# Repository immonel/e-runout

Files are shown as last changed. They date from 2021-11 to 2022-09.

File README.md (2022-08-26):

# e-runout

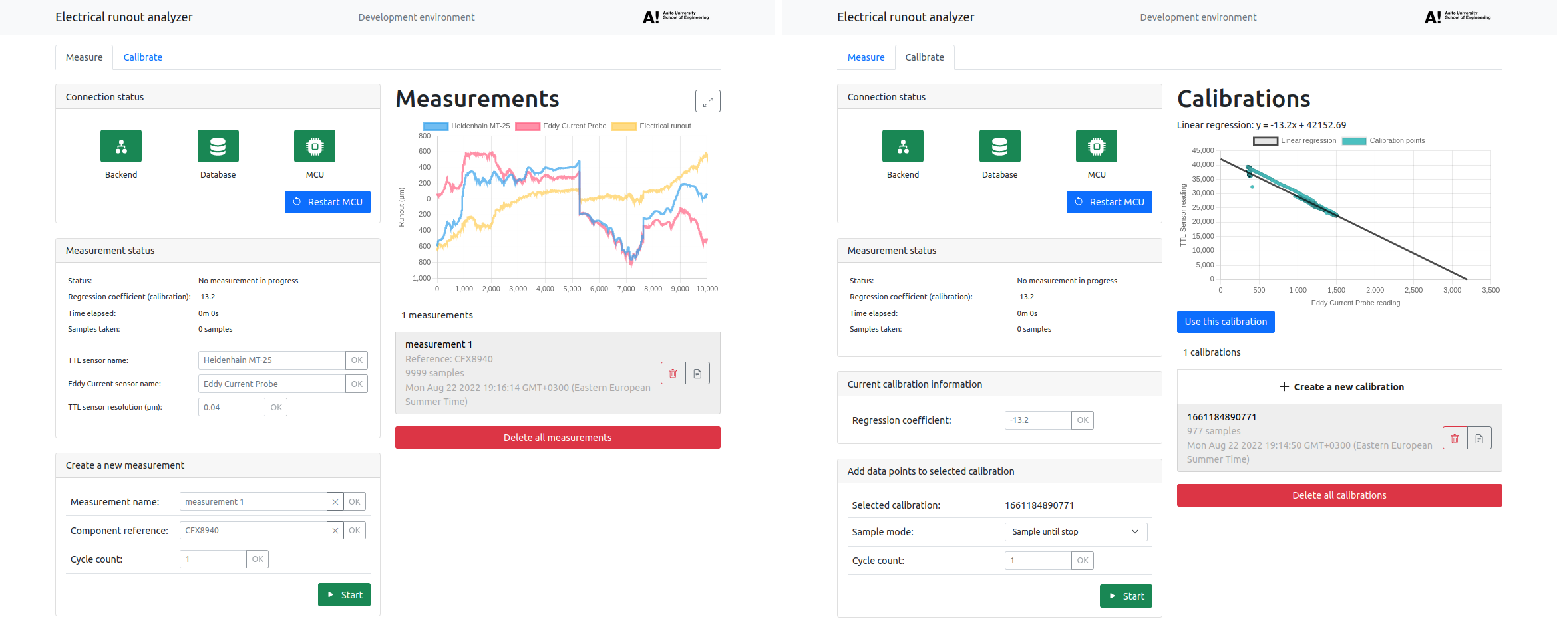
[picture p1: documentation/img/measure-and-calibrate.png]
Screenshot of the app


This project is used to measure electrical runout by comparing measurements from touching probe sensors and Eddy current probes simultaneously.

Technologies and frameworks used in the project include Docker, React, Redux, Bootstrap, Node.js, Express, MongoDB and Socket.IO.

### Project structure
[client/](client/)  
Frontend React app code

[documentation/](documentation/)  
Documentation files

[hardware/](hardware/)  
PCB schematics

[mongodb/](mongodb/)  
MongoDB init scripts

[server/](server/)  
Backend Node.js app code

[teensy/](teensy/)  
Teensy microcontroller C++ code

----
## Getting started

### Production

1. Fill out environment variables and rename the .env file:
```sh
$ mv .example.env .env
```

2. Start up the docker-compose stack:
```sh
$ docker-compose up
```

**NOTE:** Please keep in mind that buiding the `erunout` Docker image on Raspberry Pi will take a LONG time (~1h).

The application creates a Wi-Fi access point with environment variables `SSID` and `PASSPHRASE` given in the `.env` file.

IP address for the application is `10.0.10.1` by default and can be accessed after connecting to the WLAN network.

```
TODO: WAN access is currently not working on the wireless access point
```

### Development

1. Rename the .env file:
```sh
$ mv .env.example .env
```

2. Start up the development database:
```sh
$ docker-compose -f docker-compose.dev.yml up
```

3. Start up the development backend server (in the `server` folder):
```sh
server $ npm install
server $ npm run dev
```

4. Start up the development frontend server (in `client` folder):
```sh
client $ npm install
client $ npm start
```

5. Navigate to the development app at `localhost:3001`. The backend server is accessible from `localhost:3000` and the database admin interface from `localhost:8081`.

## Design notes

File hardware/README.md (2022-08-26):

# PCB schematics

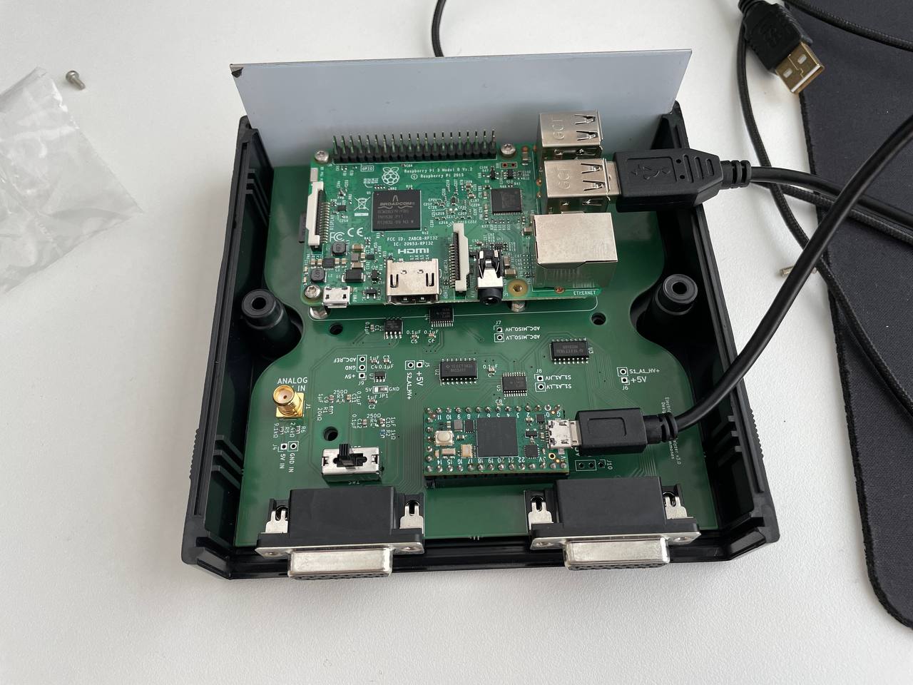
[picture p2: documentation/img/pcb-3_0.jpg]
Image of the PCB


This folder contains the KiCad (6.0) schematics for the project. The most recent schematics are named `erun2`. The project file is `erun2.kicad_pro` which is the easiest way to open all the schematics. The wiring diagram is in `erun2.kicad_sch` and PCB in `erun2.kicad_pcb`.

### Data sheets of components used
- [TXB0108PWR](https://www.ti.com/lit/ds/symlink/txb0108.pdf) Voltage level translator (5V->3.3V)
- [MC3486N](https://www.ti.com/lit/ds/symlink/mc3486.pdf) Differential line receiver
- [MCP3301](https://ww1.microchip.com/downloads/aemDocuments/documents/APID/ProductDocuments/DataSheets/21700E.pdf) 13-bit analog-to-digital converter
- [TPS79147DVBT](https://www.ti.com/lit/ds/symlink/tps79147-ep.pdf) Low-dropout regulator (WARNING: These break really easily due to ESD, be careful with these)

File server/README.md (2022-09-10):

# e-runout server

This Node.js backend uses Socket.IO to communicate with the client and 'serialport' npm package to communicate with the Teensy microcontroller. Measurements are saved into a MongoDB database using the 'mongoose' npm library. More information about the libraries used can be found from [helpful-links.md](../documentation/helpful-links.md). 

## Getting started

### Development

The development server can be started by running `npm install` and `npm run dev`. The default port is 3000.

### Production

The backend server relies on other services to be running. Please refer to the [repository README](../README.md).

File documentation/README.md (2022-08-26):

# Documentation

This folder contains useful information and documentation about the `e-runout` project. Please note, however, that README-files in the root of the project and in subfolders contain most of the technical details:

[README.md](../README.md)  
[client/README.md](../client/README.md)  
[server/README.md](../server/README.md)  
[teensy/README.md](../teensy/README.md)  
[hardware/README.md](../hardware/README.md)

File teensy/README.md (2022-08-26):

# erunout -- Teensy microcontroller

This project uses the Teensy 4.0 microcontroller for reading the sensors, mostly because it has [hardware support](https://forum.pjrc.com/threads/58478-Teensy-4-x-H-W-Quadrature-Encoder-Library) for quadrature signals.

The Teensy will idle until it receives commands through the serial port. Supported commands are:

- `SAMPLE_CYCLES <count>`: Sample integer amount of cycles (full rotary encoder revolutions)
- `SAMPLE_UNTIL`: Sample data points until `STOP` command is received
- `SAMPLE_ONCE`: Sample a single data point and stop
- `STOP`: Stop reading and sending data points
- `REBOOT`: Reboots the microcontroller
- `ZERO`: Resets the touching TTL probe's value to zero.

## Reading the sensors

The TTL signals are read using the [Teensy hardware quadrature library](https://github.com/mjs513/Teensy-4.x-Quad-Encoder-Library). The Eddy current sensor's signal is read using [SPI](https://www.pjrc.com/teensy/td_libs_SPI.html).

## Data point format

The data point is sent to the Raspberry Pi using serial port as follows:

```
+--------------------------------+----------------+----------------+
| TTL sensor                     | Eddy probe     | Cycle          |
| 32 bits                        | 16 bits        | 16 bits        |
+--------------------------------+----------------+----------------+
```

The values are bit shifted into a 64-bit integer and parsed in the Node.js backend. The data points are delimited by a newline characted `\n`.

### Notes about the data format

- `Cycle` indicates the current cycle in a running measurement. It is currently not used in the backend, but it could have use in dividing the measurement into cycles or displaying in the chart where the cycle changes
- The data point is sent through serial with `Serial.println` encoded in ASCII. It is not ideal and the bit shifting is currently kind of useless since the values in the data point could just be delimited with a character, `18423,2495,1` for example. The original purpose was to send the bit-shifted 64-bit integer as binary, but delimiting separate data points reliably (and space efficiently) is not trivial and was left for future implementation.
- Sign of the Eddy current probe value is currently discarded since the negative values in voltage have no meaning in this application.

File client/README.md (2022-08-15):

# Electrical runout analyzer -- frontend

Frontend of the `e-runout` project is a SPA (single page application) built with React and Bootstrap. 

The frontend uses WebSockets to communicate with the backend. ASyncAPI documentation about the WebSocket API can be found in [documentation/asyncapi.yaml](../documentation/asyncapi.yaml). It is recommended to use e.g. [AsyncAPI Studio](https://studio.asyncapi.com/) to view the API documentation.

## The webapp

The webapp contains two pages: `Measure` and `Calibrate`.

### Measure

The `Measure` page is used to create and view measurements. When you press the `Start` button, a new measurement is created with the parameters given in the webapp. Data points are not recorded until the rotary encoder hits the trigger point. After the trigger point, data points are sampled and saved to the new measurement. If either the configured cycle count is reached or the measurement is stopped, the newly created measurement will be added to the measurement list.

**NOTE: Remember to calibrate the Eddy current sensor on the `Calibrate` tab before measuring for the first time!**

### Calibrate

The `Calibrate` page is used to create and view calibrations. **Calibrations use the same data structure internally as regular measurements.** As opposed to the `Measure` page, data points are added to existing calibrations. Thus, you will need to first create an empty calibration and select it to add data points. To set the calibration cofficient, press the `Use calibration` button.

## Getting started
### Development

To start the frontend development server, run the following commands in the `client` folder.

1. `npm install`
2. `npm start`

The development server can be accessed from `localhost:3001` by default.

### Production build

To build a production webapp, run `npm run build` and it will be built into `build` folder. The backend serves contents from this folder in development environment. 

It is recommended, however, to use the production environment using `docker-compose` as described in the project root [README.md](../README.md) file.

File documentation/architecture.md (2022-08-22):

# Architecture

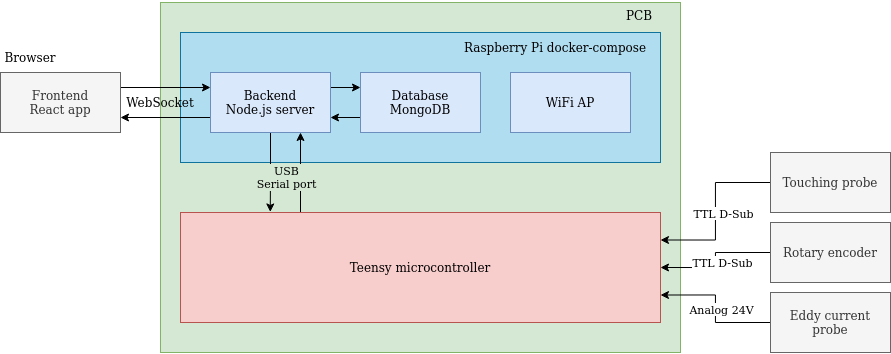
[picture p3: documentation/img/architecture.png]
architecture image


## docker-compose stack

The production `docker-compose` stack consists of three containers:
- `erunout`
- `mongo` [Docker Hub](https://hub.docker.com/_/mongo)
- `rpi-hostap` [Docker Hub](https://hub.docker.com/r/sdelrio/rpi-hostap)

The development `docker-compose` stack consists of two containers:
- `mongo` [Docker Hub](https://hub.docker.com/_/mongo)
- `mongo-express` [Docker Hub](https://hub.docker.com/_/mongo-express)

## erunout

The backend server running on the Raspberry Pi uses WebSockets to communicate with the client. Refer to [AsyncAPI documentation](./asyncapi.yaml) for more detailed information.

## Teensy

The Teensy microcontroller is connected to the Raspberry Pi using USB Serial port.

The TTL signals are connected to Teensy's digital pins supporting hardware quadrature. The analog signal is converted to a digital signal using on-board ADC and passed on to the Teensy using SPI.

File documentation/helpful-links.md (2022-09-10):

# Helpful links to external documentations

- [Heidenhain TTL interface](https://www.heidenhain.fi/fileadmin/pdb/media/img/1078628-23_Interfaces_en_web.pdf)
- [Teensy 4.0](https://www.pjrc.com/store/teensy40.html)
- [Teensy Hardware Quadrature library](https://github.com/mjs513/Teensy-4.x-Quad-Encoder-Library)
- [rpi-hostap](https://github.com/sdelrio/rpi-hostap)
- [React Bootstrap documentation](https://react-bootstrap.github.io/)
- [Full stack open course materials](https://fullstackopen.com/)
- [Socket.IO](https://socket.io/)
- [serialport npm](https://serialport.io/docs/)

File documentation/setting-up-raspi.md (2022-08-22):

# Setting up Raspberry Pi for e-runout

It is recommended to install Ubuntu Server for running the application. Note that internet connection is required to pull the repository and Docker images.

### Pulling the repository

```sh
$ git pull https://version.aalto.fi/gitlab/tiainet2/e-runout.git
```

### Wifi-AP

The `wifi-ap` container requires `wpa_supplicant` to be disabled, which controls the `wlan0` interface by default. Please refer to [sdelrio/rpi-hostap](https://github.com/sdelrio/rpi-hostap) documentation for more details.

### Startup script

It is recommended to setup the application to run on startup with e.g. crontab or an init script.

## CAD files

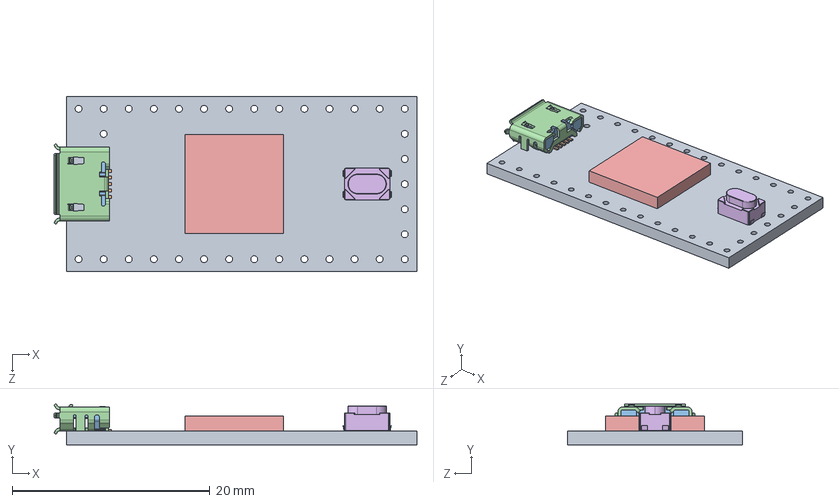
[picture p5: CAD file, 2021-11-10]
hardware/erun/teensy.pretty-master/Teensy_4.0_Assembly.STEP
36.8 x 4.12 x 17.7 mm
Teensy_4.0_PCB
Micro USB-B Female 5Pin SMD
NXP iMXRT1062
SKRPACE010 v4

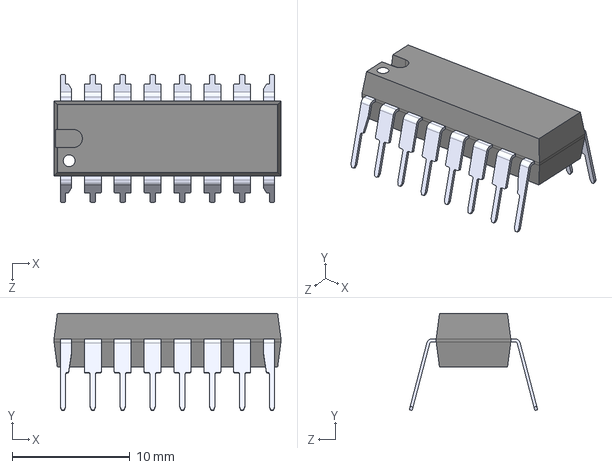
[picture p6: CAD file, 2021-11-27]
hardware/erun/MC3486N/MC3486N.step
19.3 x 8.25 x 10.9 mm

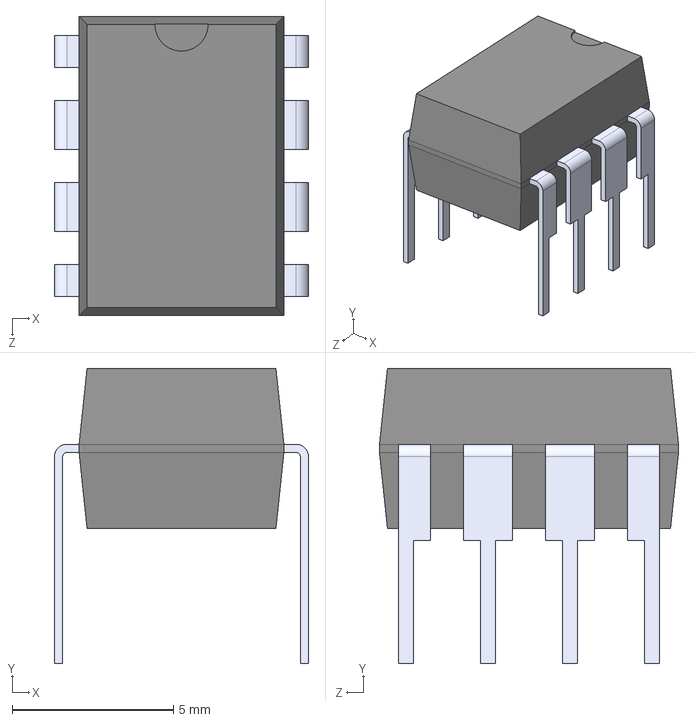
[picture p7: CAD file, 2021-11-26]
hardware/erun/MCP3301/MCP3301-BI_P.step
7.87 x 9.14 x 9.27 mm

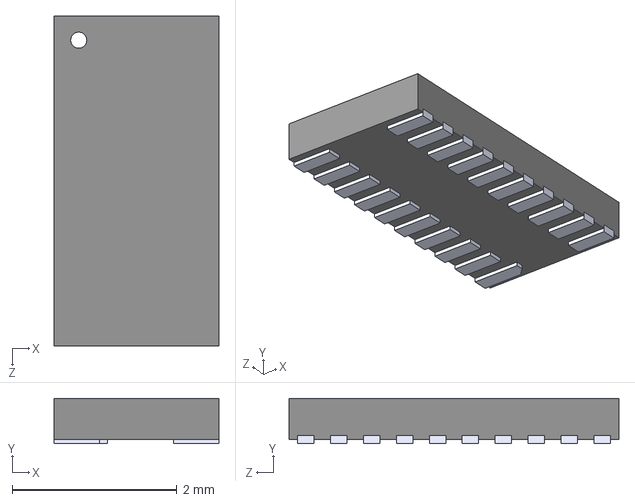
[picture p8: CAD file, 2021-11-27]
hardware/erun/TXB0108DQSR/TXB0108DQSR.step
2.00 x 0.55 x 4.00 mm

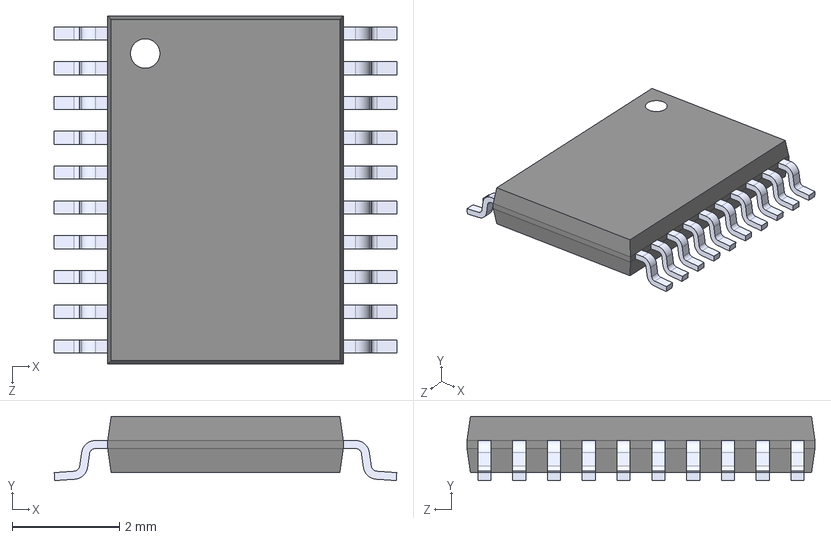
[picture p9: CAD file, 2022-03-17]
hardware/erun/TXB0108PWR/TXB0108PWR.step
6.40 x 1.20 x 6.50 mm

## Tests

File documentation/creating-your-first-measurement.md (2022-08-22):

# Creating your first measurement with erunout

## Calibration

When first opening the application, you have to create a calibration. The calibration (regression coefficient) ties your touching probe and Eddy current probe readings together so that they are comparable.

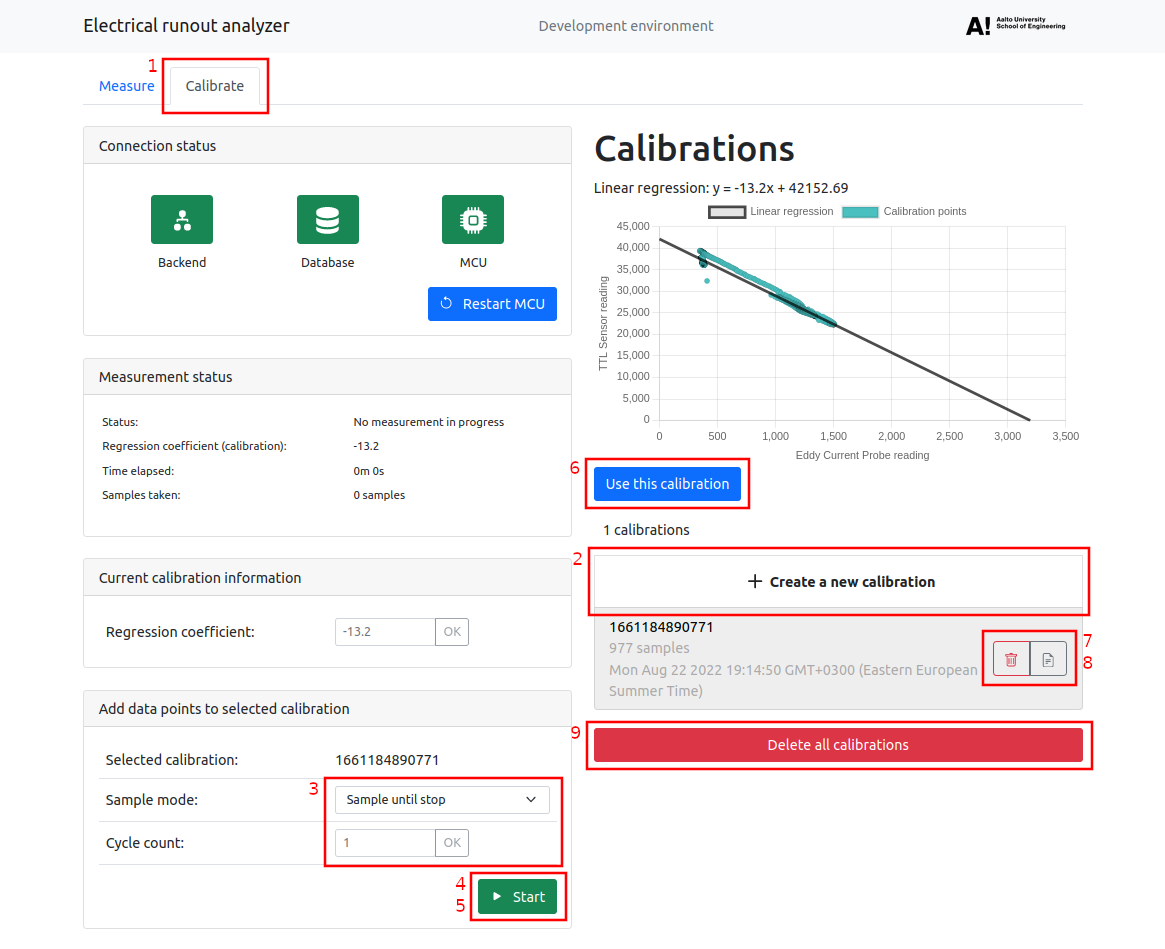
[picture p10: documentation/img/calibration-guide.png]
Calibration guide image


1. Switch to the `Calibrate` tab

2. Click the `Create a new calibration` button and select the created calibration

3. Select a sample mode (and cycle count if sampling using cycles. Remember to click `OK` or press `Enter` to set the value).

4. Click the `Start` button. You can now rotate the measured object and the application will collect data points.

5. Collect data points until the measurement is stopped automatically, or click the `Stop` button to stop the measurement.

6. Click the `Use this calibration` button on the selected calibration. If linear regression cannot be calculated from the data points, the button is disabled. In this case, you can either add more data points to the calibration or create a new calibration.

7. View or save the raw measurement JSON data by clicking the file icon button.

8. Delete a calibration by clicking the trash icon button.

9. Double-click the `Delete all calibrations` button to delete all saved calibrations.

```
NOTE: Eddy current readings near its maximum range are discarded from the linear regression to avoid data points outside of its measuring range to affect the calibration negatively.
```

---

## Measurement

Now that you've set the calibration (regression coefficient), you can create your first measurement.

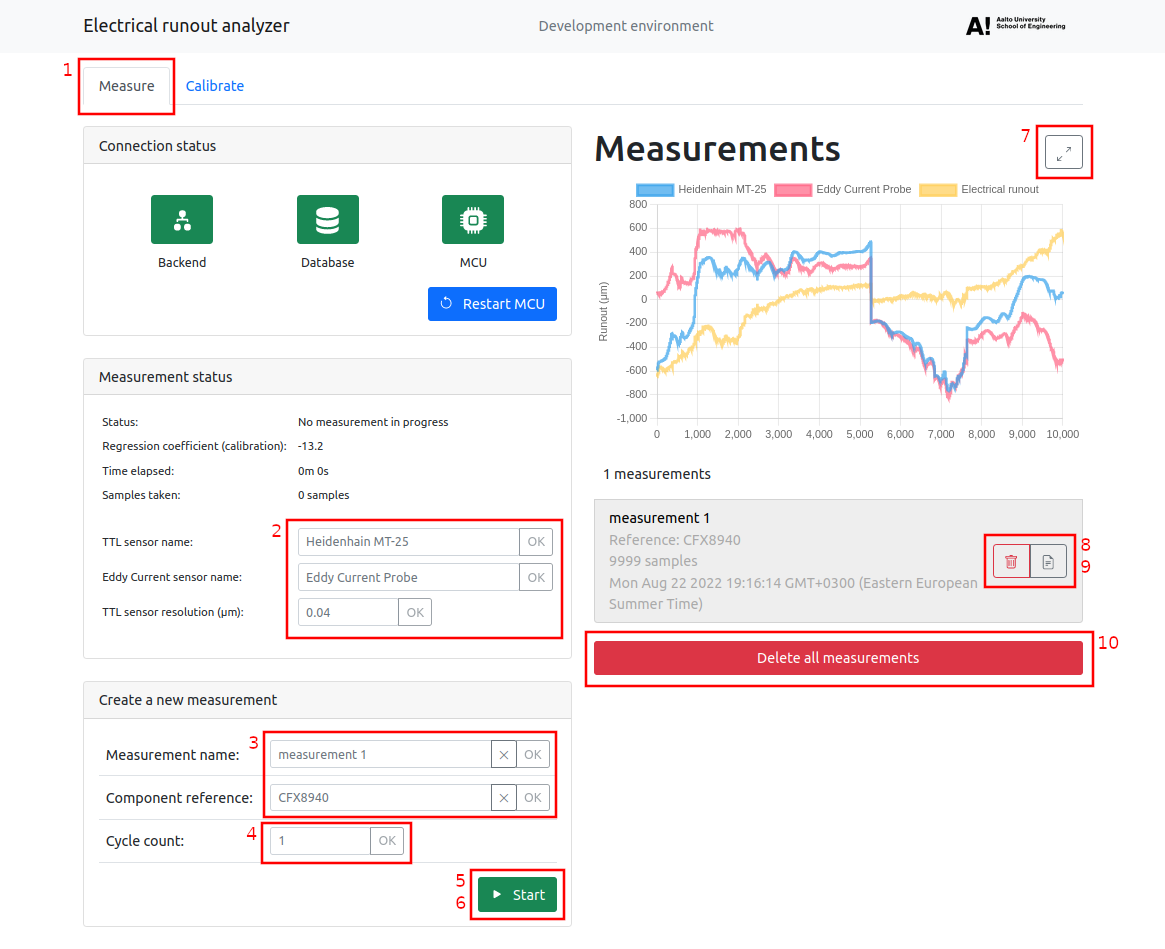
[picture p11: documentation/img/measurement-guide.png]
Measurement guide image


1. Switch to the `Measure` tab

2. Set `TTL sensor name`, `Eddy current sensor name` and `TTL sensor resolution`. Remember to click `OK` or press `Enter` to set the values.

3. (optional) Set a name for the measurement and a component reference to identify the measured object.

4. Set the cycle count. This will determine the number of full revolutions before the measurement is stopped automatically.

5. Click the `Start` button. You can now rotate the measured object and the application will collect data points.

6. Collect data points until the measurement is stopped automatically, or click the `Stop` button to stop the measurement.

7. You can now select the measurement and view the chart showing runout values. The runout is calculated by substracting average from the dataset and scaled by the `TTL sensor resolution`. You can also expand the chart by clicking the expand button and also print it out when expanded.

8. View or save the raw measurement JSON data by clicking the file icon button.

9. Delete a measurement by clicking the trash icon button.

10. Double-click the `Delete all measurements` button to delete all saved measurements.

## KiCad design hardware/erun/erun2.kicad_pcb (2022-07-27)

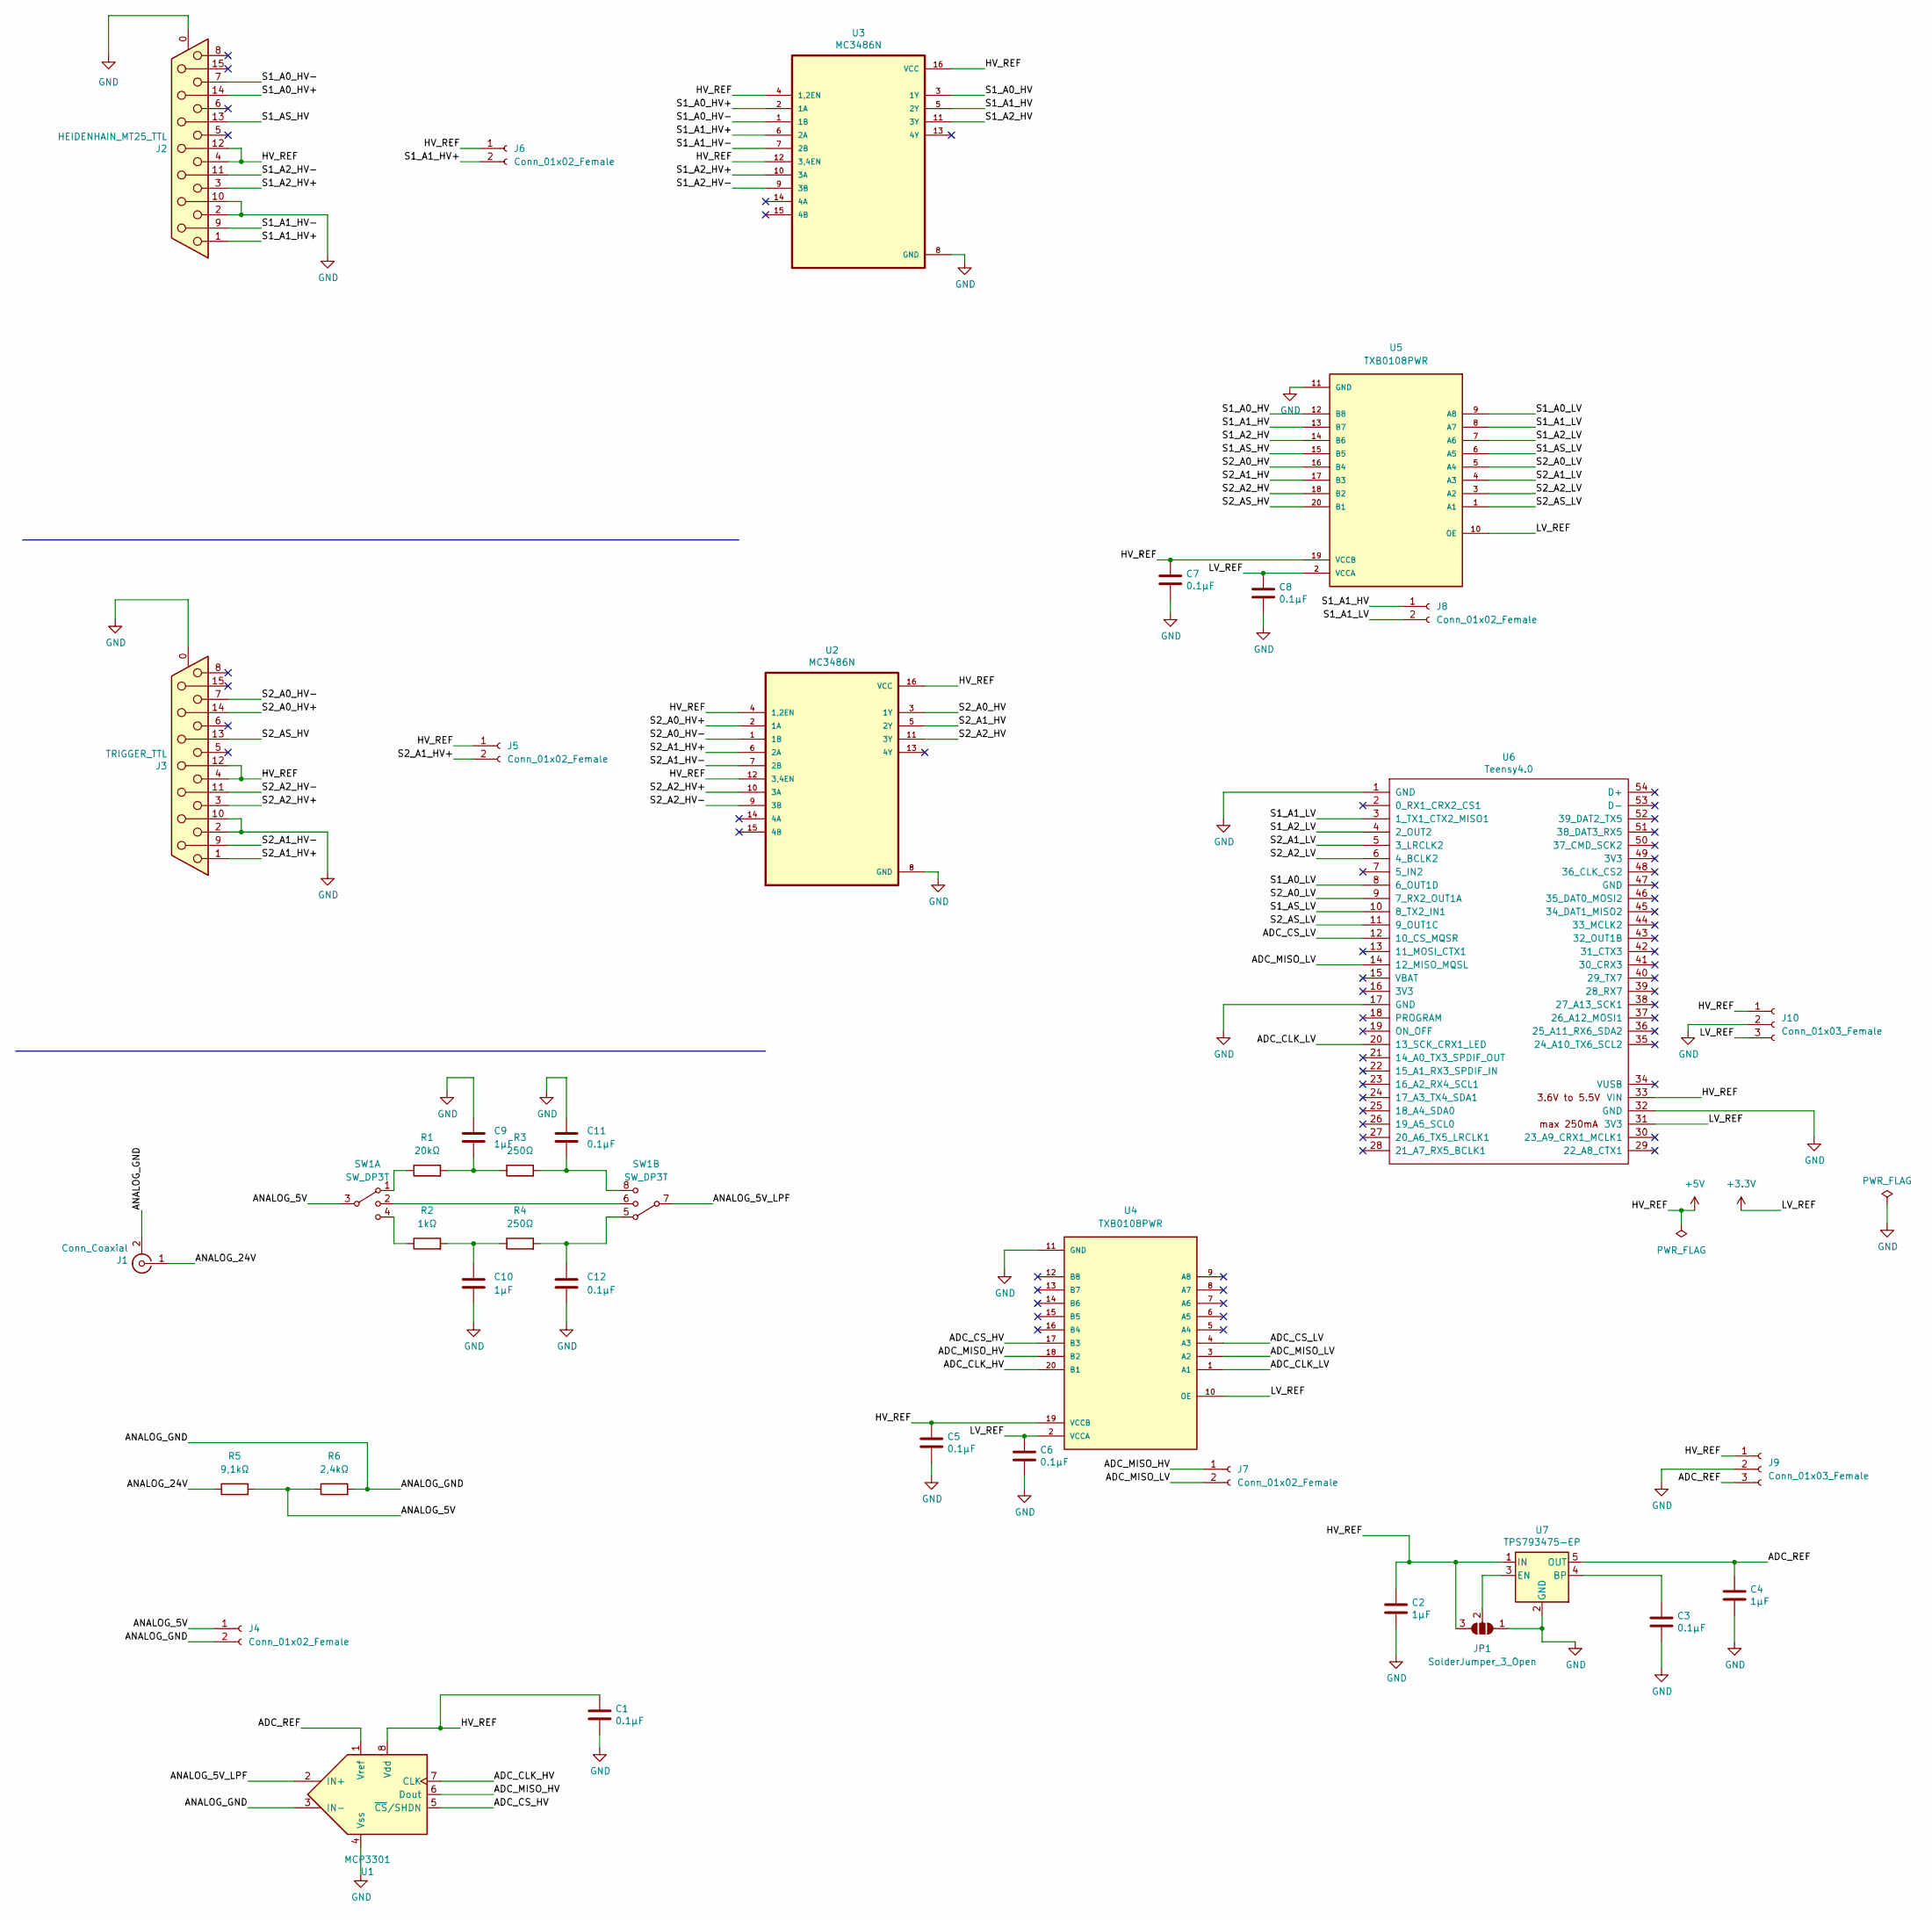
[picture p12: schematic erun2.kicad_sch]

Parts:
C1, C3, C5, C6, C7, C8, C11, C12: 0.1μF; C_0603_1608Metric
C2, C4, C9, C10: 1μF; C_0603_1608Metric
J1: Conn_Coaxial; SMA_Amphenol_132134-16_Vertical
J2: HEIDENHAIN_MT25_TTL; DSUB-15_Female_Horizontal_P2.77x2.84mm_EdgePinOffset7.70mm_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
J3: TRIGGER_TTL; DSUB-15_Female_Horizontal_P2.77x2.84mm_EdgePinOffset7.70mm_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
J4, J5, J6, J7, J8: Conn_01x02_Female; PinHeader_1x02_P2.54mm_Vertical
J9, J10: Conn_01x03_Female; PinHeader_1x03_P2.54mm_Vertical
JP1: SolderJumper_3_Open; SolderJumper-3_P1.3mm_Open_Pad1.0x1.5mm_NumberLabels
R1: 20kΩ; R_0603_1608Metric
R2: 1kΩ; R_0603_1608Metric
R3, R4: 250Ω; R_0603_1608Metric
R5: 9,1kΩ; R_0603_1608Metric
R6: 2,4kΩ; R_0603_1608Metric
SW1: SW_DP3T
U1: MCP3301; SOIC-8_3.9x4.9mm_P1.27mm
U2, U3: MC3486N; SOIC-16_4.55x10.3mm_P1.27mm
U4, U5: TXB0108PWR; SOP65P640X120-20N; PARTREV H
U6: Teensy4.0; Teensy40
U7: TPS793475-EP; SOT-23-5

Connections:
+3V3: C6.1, C8.1, J10.3, U4.2 (VCCA), U4.10 (OE), U5.2 (VCCA), U5.10 (OE), U6.31 (3V3)
+5V: C1.1, C2.1, C5.1, C7.1, J2.4, J2.12, J3.4, J3.12, J5.1, J6.1, J9.1, J10.1, JP1.3 (B), U1.8 (Vdd), U2.4 (1,2EN), U2.12 (3,4EN), U2.16 (VCC), U3.4 (1,2EN), U3.12 (3,4EN), U3.16 (VCC), U4.19 (VCCB), U5.19 (VCCB), U6.33 (VIN), U7.1 (IN)
/ADC_CLK_HV: U1.7 (CLK), U4.20 (B1)
/ADC_CLK_LV: U4.1 (A1), U6.20 (13_SCK_CRX1_LED)
/ADC_CS_HV: U1.5 (~CS/SHDN), U4.17 (B3)
/ADC_CS_LV: U4.4 (A3), U6.12 (10_CS_MQSR)
/ADC_MISO_HV: J7.1, U1.6 (Dout), U4.18 (B2)
/ADC_MISO_LV: J7.2, U4.3 (A2), U6.14 (12_MISO_MQSL)
/ADC_REF: C4.1, J9.3, U1.1 (Vref), U7.5 (OUT)
/ANALOG_5V: J4.1, R5.2, R6.1, SW1.3
/ANALOG_5V_LPF: SW1.7, U1.2 (IN+)
/ANALOG_24V: J1.1 (In), R5.1
/ANALOG_GND: J1.2 (Ext), J4.2, R6.2, U1.3 (IN-)
/S1_A0_HV: U3.3 (1Y), U5.12 (B8)
/S1_A0_HV+: J2.14, U3.2 (1A)
/S1_A0_HV-: J2.7, U3.1 (1B)
/S1_A0_LV: U5.9 (A8), U6.8 (6_OUT1D)
/S1_A1_HV: J8.1, U3.5 (2Y), U5.13 (B7)
/S1_A1_HV+: J2.1, J6.2, U3.6 (2A)
/S1_A1_HV-: J2.9, U3.7 (2B)
/S1_A1_LV: J8.2, U5.8 (A7), U6.3 (1_TX1_CTX2_MISO1)
/S1_A2_HV: U3.11 (3Y), U5.14 (B6)
/S1_A2_HV+: J2.3, U3.10 (3A)
/S1_A2_HV-: J2.11 (P111), U3.9 (3B)
/S1_A2_LV: U5.7 (A6), U6.4 (2_OUT2)
/S1_AS_HV: J2.13, U5.15 (B5)
/S1_AS_LV: U5.6 (A5), U6.10 (8_TX2_IN1)
/S2_A0_HV: U2.3 (1Y), U5.16 (B4)
/S2_A0_HV+: J3.14, U2.2 (1A)
/S2_A0_HV-: J3.7, U2.1 (1B)
/S2_A0_LV: U5.5 (A4), U6.9 (7_RX2_OUT1A)
/S2_A1_HV: U2.5 (2Y), U5.17 (B3)
/S2_A1_HV+: J3.1, J5.2, U2.6 (2A)
/S2_A1_HV-: J3.9, U2.7 (2B)
/S2_A1_LV: U5.4 (A3), U6.5 (3_LRCLK2)
/S2_A2_HV: U2.11 (3Y), U5.18 (B2)
/S2_A2_HV+: J3.3, U2.10 (3A)
/S2_A2_HV-: J3.11 (P111), U2.9 (3B)
/S2_A2_LV: U5.3 (A2), U6.6 (4_BCLK2)
/S2_AS_HV: J3.13, U5.20 (B1)
/S2_AS_LV: U5.1 (A1), U6.11 (9_OUT1C)
GND: C1.2, C2.2, C3.2, C4.2, C5.2, C6.2, C7.2, C8.2, C9.1, C10.2, C11.1, C12.2, J2.0 (PAD), J2.2, J2.10, J3.0 (PAD), J3.2, J3.10, J9.2, J10.2, JP1.1 (A), U1.4 (Vss), U2.8 (GND), U3.8 (GND), U4.11 (GND), U5.11 (GND), U6.1 (GND), U6.17 (GND), U6.32 (GND), U7.2 (GND)
unnamed: C3.1, U7.4 (BP)
unnamed: C9.2, R1.2, R3.1
unnamed: C10.1, R2.2, R4.1
unnamed: C11.2, R3.2, SW1.8
unnamed: C12.1, R4.2, SW1.5
unnamed: JP1.2 (C), U7.3 (EN)
unnamed: R1.1, SW1.1
unnamed: R2.1, SW1.4
unnamed: SW1.2, SW1.6

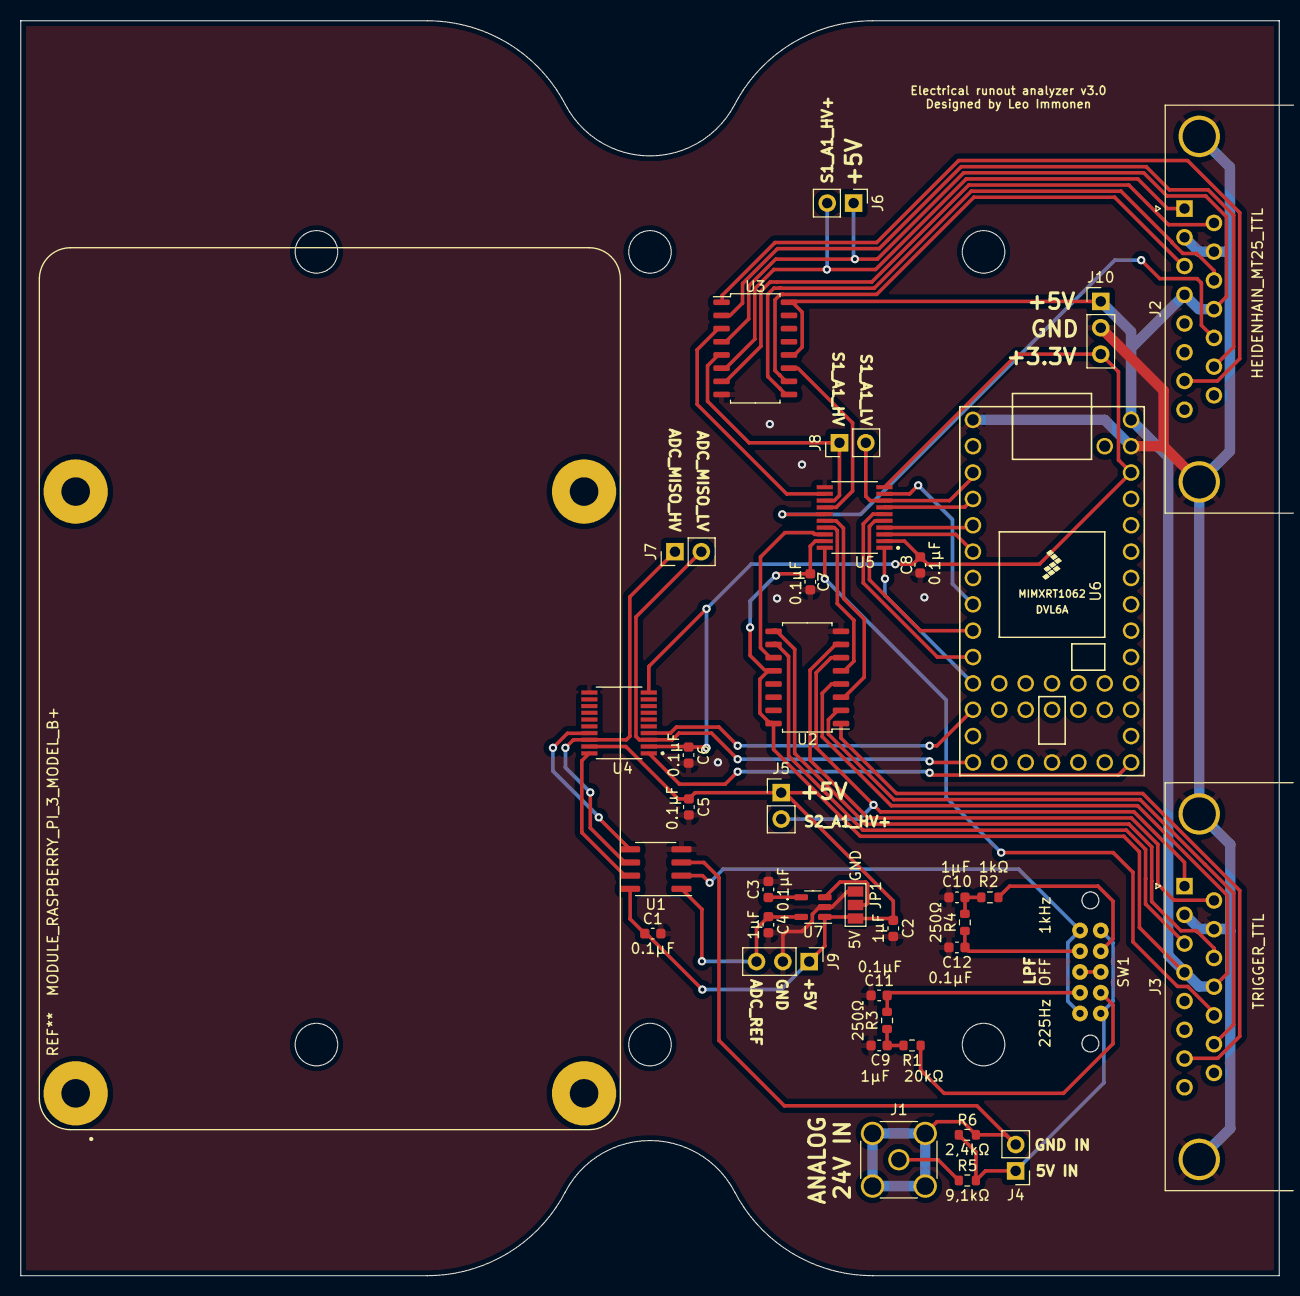
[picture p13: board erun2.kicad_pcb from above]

Board: 2 copper layers, 121.3 x 120.9 mm, 37 parts (0 on the bottom side), 51 nets.

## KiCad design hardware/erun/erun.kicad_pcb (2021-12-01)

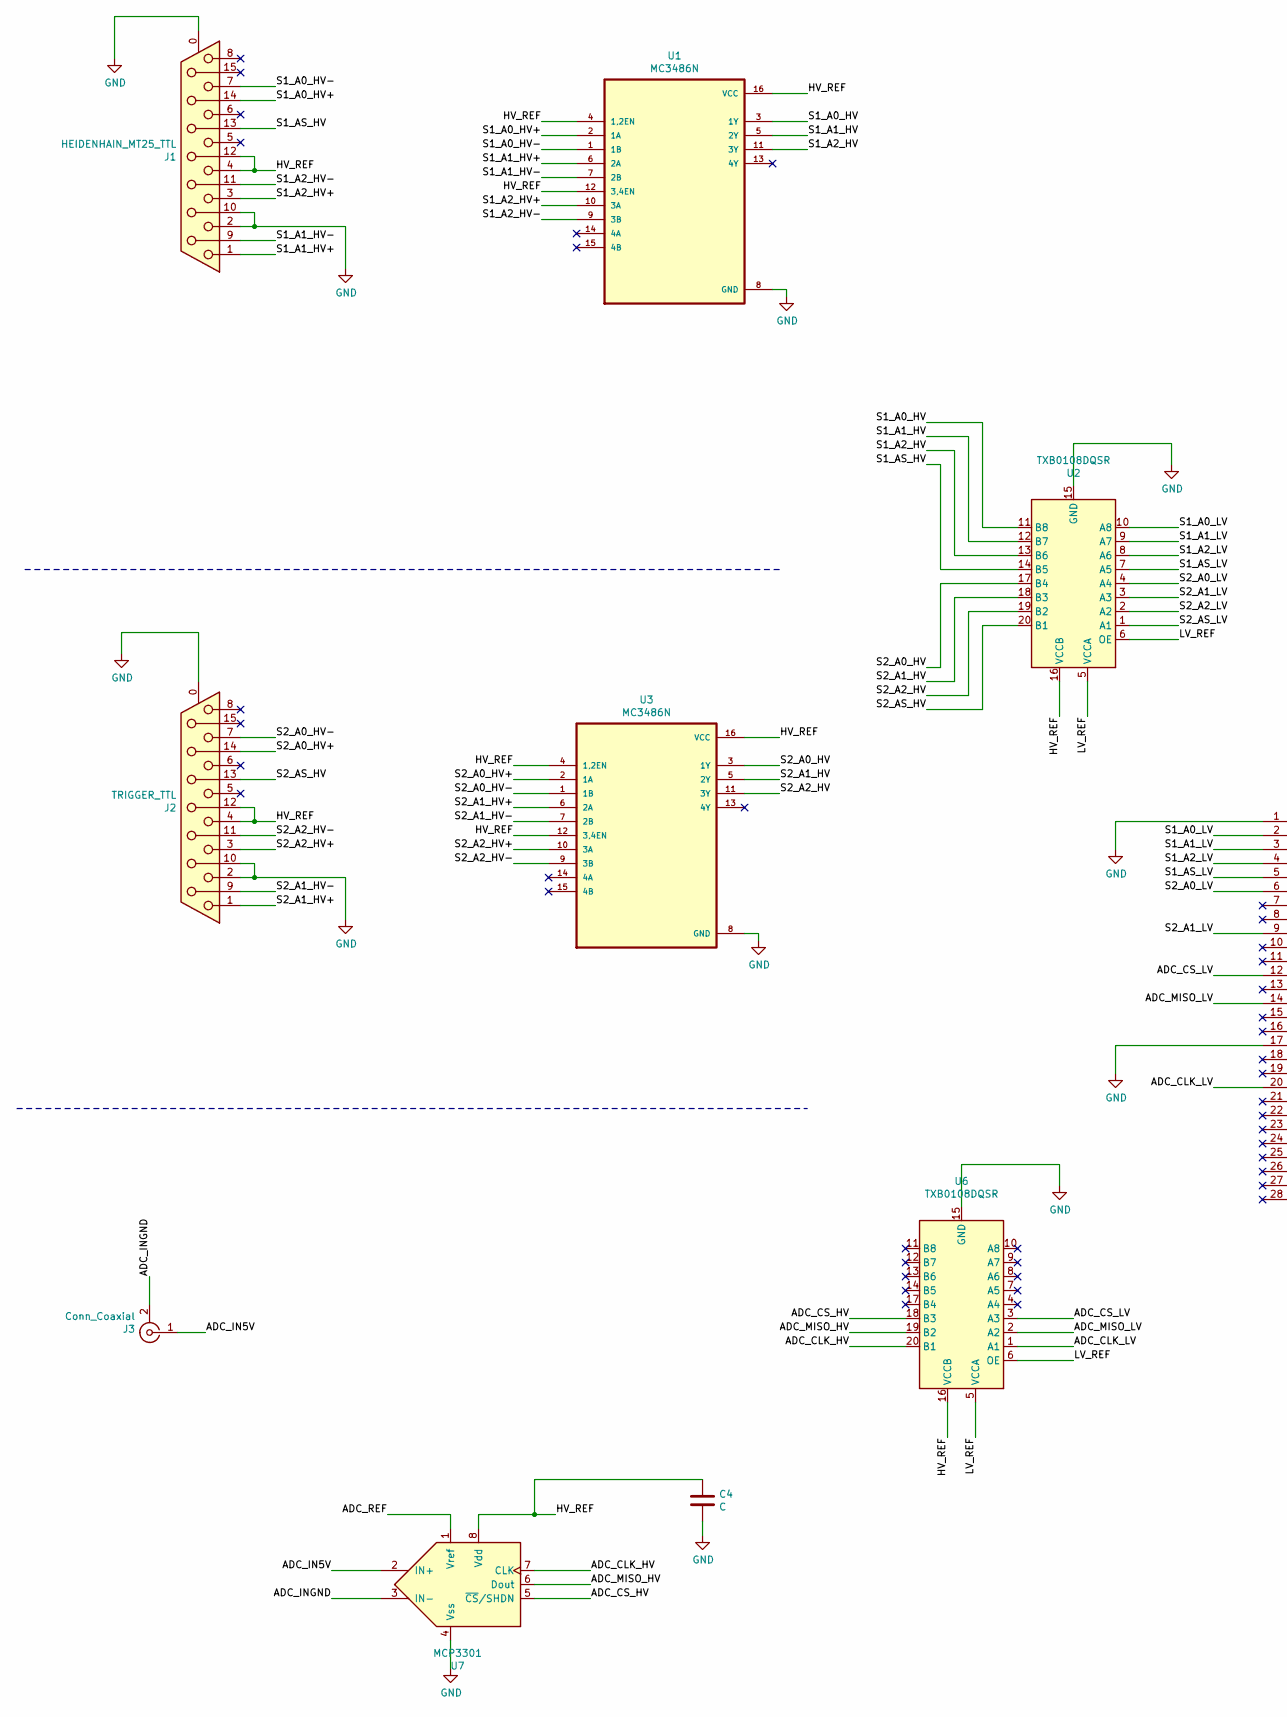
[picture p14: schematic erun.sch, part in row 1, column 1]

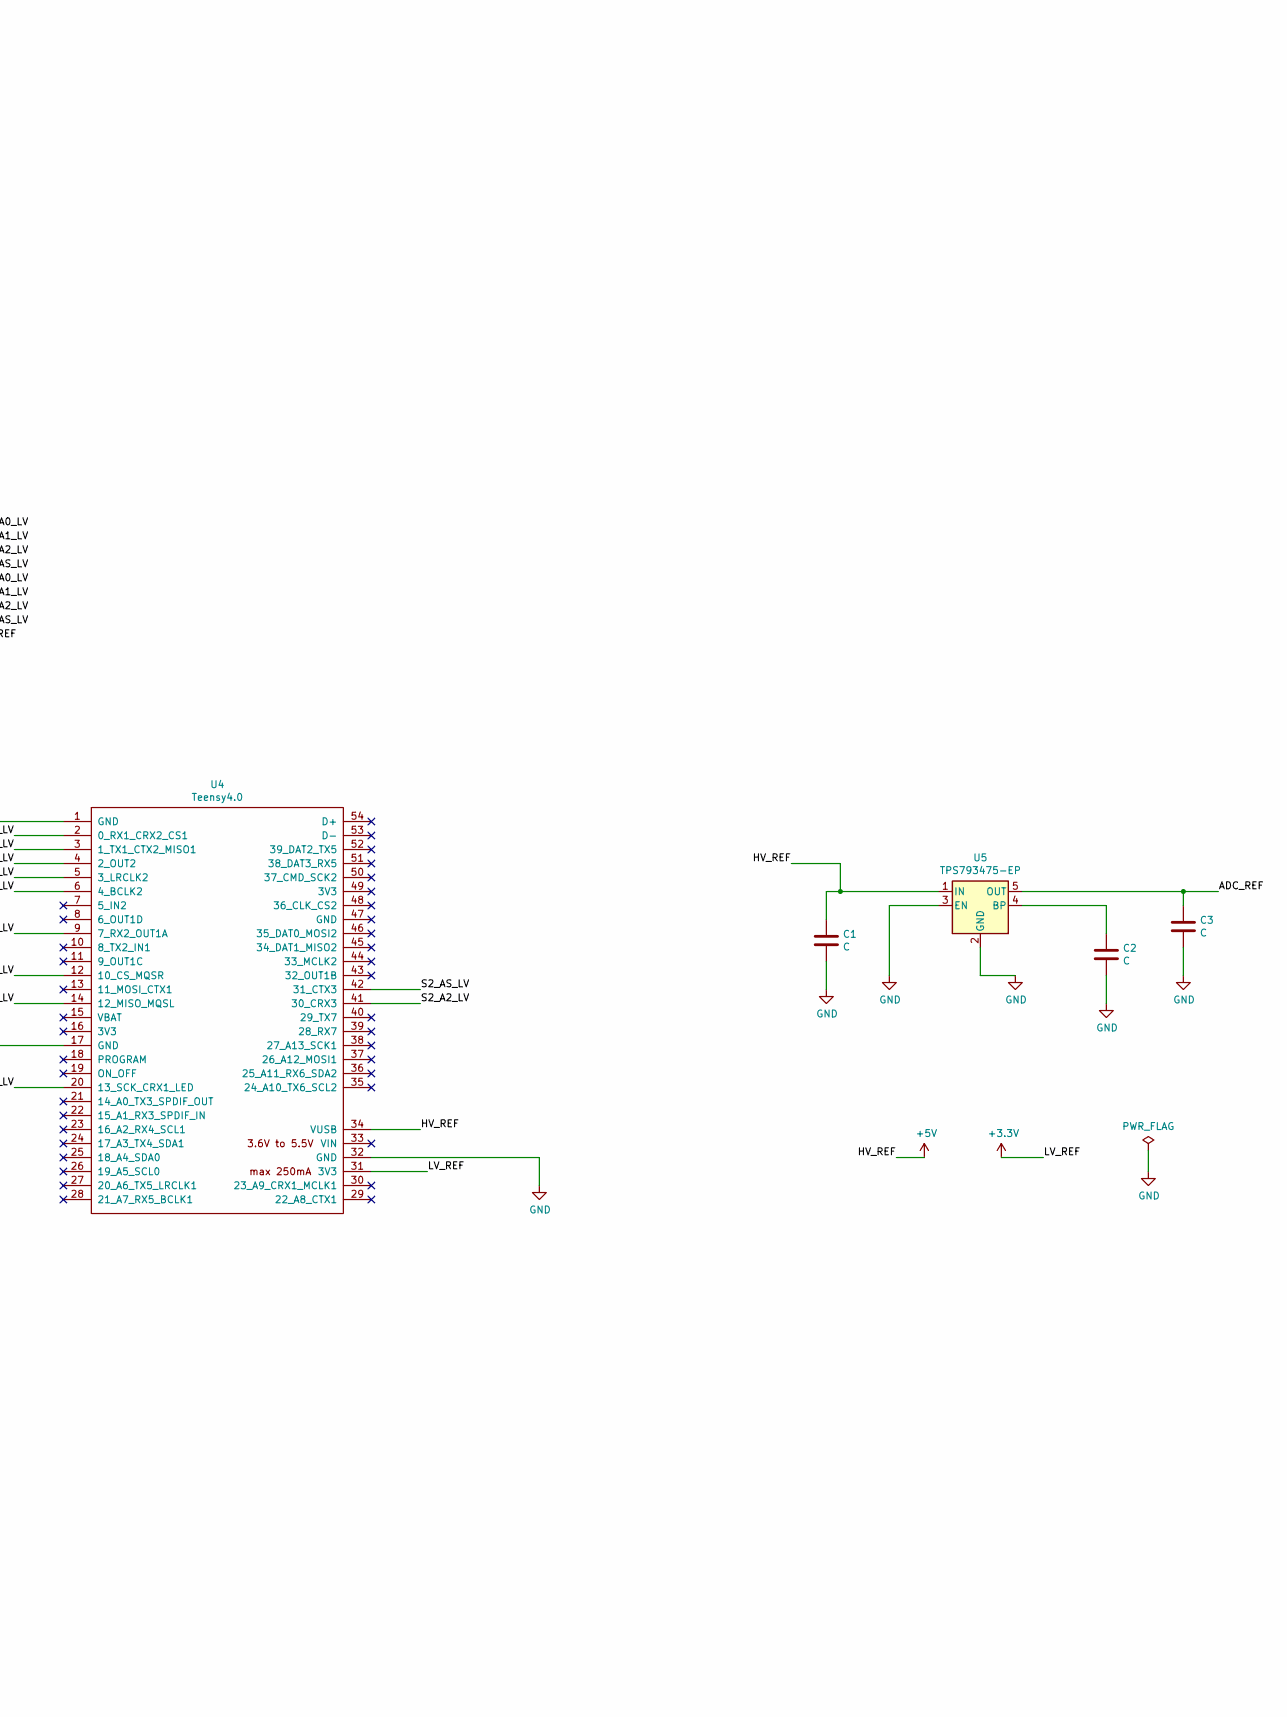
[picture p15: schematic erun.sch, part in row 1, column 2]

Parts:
C1, C2, C3, C4: C; C_0603_1608Metric
J1: HEIDENHAIN_MT25_TTL; DSUB-15_Female_Horizontal_P2.77x2.84mm_EdgePinOffset7.70mm_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
J2: TRIGGER_TTL; DSUB-15_Female_Horizontal_P2.77x2.84mm_EdgePinOffset7.70mm_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
J3: Conn_Coaxial; SMA_Amphenol_132134-14_Vertical
U1, U3: MC3486N; SOIC-16_4.55x10.3mm_P1.27mm
U2, U6: TXB0108DQSR; TSSOP-20_4.4x6.5mm_P0.65mm
U4: Teensy4.0; Teensy40
U5: TPS793475-EP; SOT-23-5
U7: MCP3301; MSOP-8_3x3mm_P0.65mm

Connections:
+3V3: U2.5 (VCCA), U2.6 (OE), U4.31 (3V3), U6.5 (VCCA), U6.6 (OE)
+5V: C1.1, C4.1, J1.4, J1.12, J2.4, J2.12, U1.4 (1,2EN), U1.12 (3,4EN), U1.16 (VCC), U2.16 (VCCB), U3.4 (1,2EN), U3.12 (3,4EN), U3.16 (VCC), U4.34 (VUSB), U5.1 (IN), U6.16 (VCCB), U7.8 (Vdd)
/ADC_CLK_HV: U6.20 (B1), U7.7 (CLK)
/ADC_CLK_LV: U4.20 (13_SCK_CRX1_LED), U6.1 (A1)
/ADC_CS_HV: U6.18 (B3), U7.5 (~CS~/SHDN)
/ADC_CS_LV: U4.12 (10_CS_MQSR), U6.3 (A3)
/ADC_IN5V: J3.1 (In), U7.2 (IN+)
/ADC_INGND: J3.2 (Ext), U7.3 (IN-)
/ADC_MISO_HV: U6.19 (B2), U7.6 (Dout)
/ADC_MISO_LV: U4.14 (12_MISO_MQSL), U6.2 (A2)
/ADC_REF: C3.1, U5.5 (OUT), U7.1 (Vref)
/S1_A0_HV: U1.3 (1Y), U2.11 (B8)
/S1_A0_HV+: J1.14, U1.2 (1A)
/S1_A0_HV-: J1.7, U1.1 (1B)
/S1_A0_LV: U2.10 (A8), U4.2 (0_RX1_CRX2_CS1)
/S1_A1_HV: U1.5 (2Y), U2.12 (B7)
/S1_A1_HV+: J1.1, U1.6 (2A)
/S1_A1_HV-: J1.9, U1.7 (2B)
/S1_A1_LV: U2.9 (A7), U4.3 (1_TX1_CTX2_MISO1)
/S1_A2_HV: U1.11 (3Y), U2.13 (B6)
/S1_A2_HV+: J1.3, U1.10 (3A)
/S1_A2_HV-: J1.11 (P111), U1.9 (3B)
/S1_A2_LV: U2.8 (A6), U4.4 (2_OUT2)
/S1_AS_HV: J1.13, U2.14 (B5)
/S1_AS_LV: U2.7 (A5), U4.5 (3_LRCLK2)
/S2_A0_HV: U2.17 (B4), U3.3 (1Y)
/S2_A0_HV+: J2.14, U3.2 (1A)
/S2_A0_HV-: J2.7, U3.1 (1B)
/S2_A0_LV: U2.4 (A4), U4.6 (4_BCLK2)
/S2_A1_HV: U2.18 (B3), U3.5 (2Y)
/S2_A1_HV+: J2.1, U3.6 (2A)
/S2_A1_HV-: J2.9, U3.7 (2B)
/S2_A1_LV: U2.3 (A3), U4.9 (7_RX2_OUT1A)
/S2_A2_HV: U2.19 (B2), U3.11 (3Y)
/S2_A2_HV+: J2.3, U3.10 (3A)
/S2_A2_HV-: J2.11 (P111), U3.9 (3B)
/S2_A2_LV: U2.2 (A2), U4.41 (30_CRX3)
/S2_AS_HV: J2.13, U2.20 (B1)
/S2_AS_LV: U2.1 (A1), U4.42 (31_CTX3)
GND: C1.2, C2.2, C3.2, C4.2, J1.0 (PAD), J1.2, J1.10, J2.0 (PAD), J2.2, J2.10, U1.8 (GND), U2.15 (GND), U3.8 (GND), U4.1 (GND), U4.17 (GND), U4.32 (GND), U5.2 (GND), U5.3 (EN), U6.15 (GND), U7.4 (Vss)
unnamed: C2.1, U5.4 (BP)

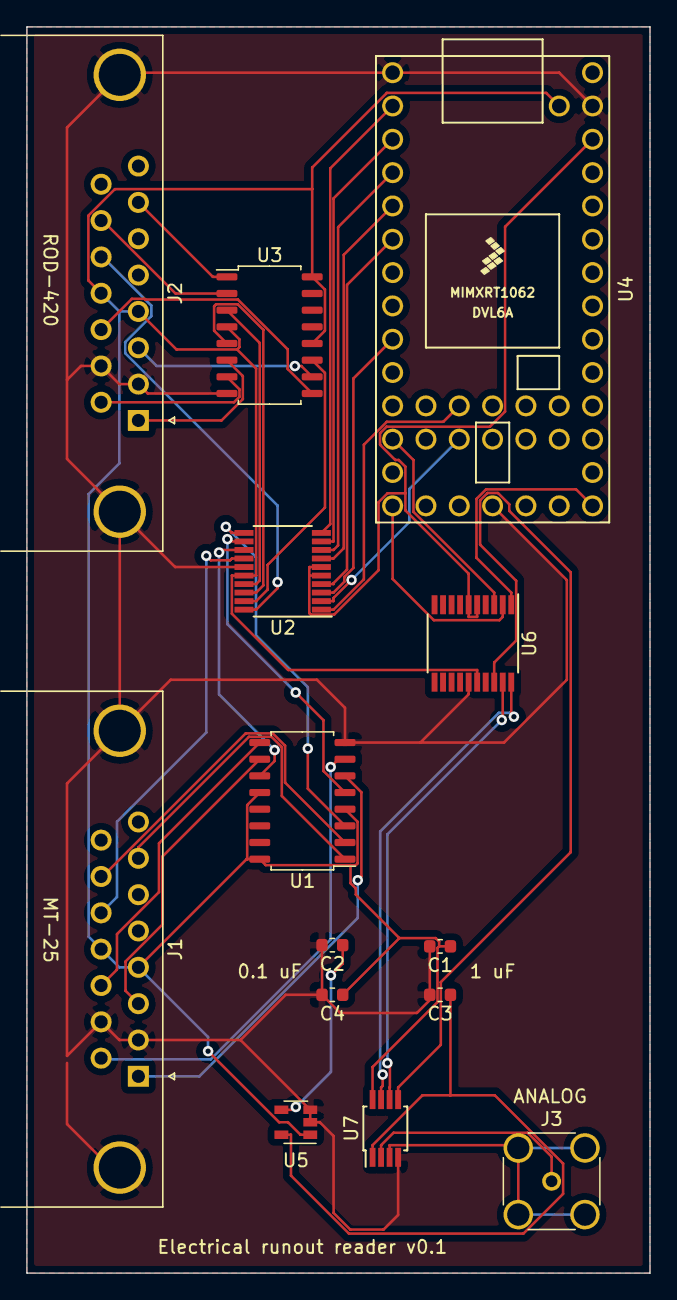
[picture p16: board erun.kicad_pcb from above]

Board: 2 copper layers, 47.5 x 95.0 mm, 14 parts (0 on the bottom side), 41 nets.

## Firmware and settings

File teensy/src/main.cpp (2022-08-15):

#include <Arduino.h>
#include "QuadEncoder.h"
#include <sstream>
#include <SPI.h>

#define SS_PIN 10

QuadEncoder heidenHain1(1, 1, 2);
QuadEncoder heidenHain2(2, 3, 4, 0, 7);

bool running = false;

void setup() {
  Serial.setTimeout(50);
  Serial.begin(1);
  Serial.println("Started up Teensy");
  
  // Setup QuadEncoders
  heidenHain1.setInitConfig();
  heidenHain1.init();
  heidenHain2.setInitConfig();
  heidenHain2.EncConfig.IndexTrigger = ENABLE;
  // heidenHain2.EncConfig.INDEXTriggerMode = RISING_EDGE;
  heidenHain2.init();

  // Setup SPI
  pinMode(SS_PIN, OUTPUT);
  digitalWrite(SS_PIN, HIGH);
  SPI.begin();
  SPI.beginTransaction(SPISettings(2000000, MSBFIRST, SPI_MODE1));
}

int16_t readSPI() {
  digitalWrite(SS_PIN, LOW);
  int16_t result = 0;
  byte data = SPI.transfer(0);

  // Extract high byte
  result += data & 0b00001111;
  result <<= 8;

  // Extract lower byte
  data = SPI.transfer(0);
  result += data;

  digitalWrite(SS_PIN, HIGH);
  return result;
}

void stopMeasurement() {
  if (running) {
    running = false;
    // Indicates end of data points
    Serial.println(0l);
    Serial.println("Measurement finished!");
  }
}

void checkStop() {
  if (Serial.available() > 0)
  {
    std::string input = std::string(Serial.readString().c_str());
    std::istringstream ss(input);

    std::string command;
    ss >> command;

    if (command == "STOP")
    {
      stopMeasurement();
    }
  }
}

void takeDataPoint() {
  static int32_t heidenHain1Value;
  static int16_t eddyValue;
  
  heidenHain1Value = heidenHain1.read();
  eddyValue = readSPI();

  /* 
    Data point format:
    +--------------------------------+----------------+----------------+
    | TTL sensor                     | Eddy probe     | Cycle          |
    | 32 bits                        | 16 bits        | 16 bits        |
    +--------------------------------+----------------+----------------+
  */
  uint64_t dataPoint =
    ((uint64_t) heidenHain1Value << 32) |
    ((uint64_t) eddyValue        << 16) |
    (uint64_t)  heidenHain2.indexCounter;

  /* Debug print */
  // Serial.printf("HH1: %d\tHH2: %d\tEddy: %d\tCycle: %d\n", 
  //   heidenHain1Value, 
  //   heidenHain2Value, 
  //   eddyValue,
  //   heidenHain2.indexCounter);
  // Serial.printf("%016llx\n", dataPoint);

  Serial.println(dataPoint);
}

void sampleOnce() {
  running = true;
  heidenHain2.indexCounter = 1;
  takeDataPoint();
  stopMeasurement();
}

void sampleCycles(size_t cycles) {
  running = true;
  int32_t heidenHain2Value;
  uint32_t maxEncoderValue = 0;

  // Reset rotary encoder
  heidenHain2.write(0);
  heidenHain2.indexCounter = 0;

  while (running) {
    heidenHain2Value = abs(heidenHain2.read());
    if (heidenHain2.indexCounter > cycles) break;

    if (heidenHain2.indexCounter > 0) {
      if (heidenHain2Value > maxEncoderValue) {
        takeDataPoint();
        maxEncoderValue = heidenHain2Value;
      }
    } else {
      // Reset rotary encoder if not yet at trigger point
      heidenHain2.write(0);
    }
    // Check if stop command has been given
    checkStop();
  }
  stopMeasurement();
}

void sampleUntilStop() {
  running = true;
  heidenHain2.indexCounter = 1;
  int32_t heidenHain2Value;
  int32_t prevEncoderValue = 0;
  while (running) {
    heidenHain2Value = abs(heidenHain2.read());
    if (heidenHain2Value != prevEncoderValue) {
      takeDataPoint();
      prevEncoderValue = heidenHain2Value;
    }
    checkStop();
  }
}

void reboot() {
  Serial.println("Restarting...");
  Serial.end();
  SCB_AIRCR = 0x05FA0004;
}

void loop() {
  if (Serial.available() > 0) {
    std::string input = std::string(Serial.readString().c_str());
    std::istringstream ss(input);

    std::string command;
    ss >> command;

    if (command == "SAMPLE_CYCLES")
    {
      size_t cycle_count;
      ss >> cycle_count;
      if (ss.fail()) {
        Serial.println("Invalid arguments.");
        Serial.println("USAGE: SAMPLE_CYCLES <cycle count>");
      } else {
        sampleCycles(cycle_count);
      }
    }
    else if (command == "SAMPLE_ONCE")
    {
      sampleOnce();
    }
    else if (command == "SAMPLE_UNTIL")
    {
      sampleUntilStop();
    }
    else if (command == "STOP") 
    {
      stopMeasurement();
    }
    else if (command == "REBOOT")
    {
      reboot();
    }
    else if (command == "ZERO")
    {
      Serial.println("Zeroing encoder...");
      heidenHain1.write(0);
    }
    else 
    {
      Serial.println("Invalid command.");
    }
  }
}

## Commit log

2021-11-10 start work on schematic
    [Teensy_4.0_Assembly.STEP, erun.kicad_pcb, erun.sch]
2021-11-18 Added teensy code
2021-11-18 Updated schematic
    [erun.sch]
2021-11-26 Updated schematics
    [MCP3301-BI_P.step, erun.kicad_pcb]
2021-11-27 Updated schematics and PCB design
    [MC3486N.step, TXB0108DQSR.step, erun.dsn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]
2021-12-01 Updated schema
    [erun.sch]
2021-12-01 erun updates
    [erun.kicad_pcb, erun.sch]
2021-12-01 E-runout HW v0.1
    [erun.dsn, erun.kicad_pcb]
2022-03-17 Board version 2.0
    [TXB0108PWR.step, erun2.dsn, erun2.kicad_pcb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]
2022-03-23 Fixed clearance issues
    [erun2.kicad_pcb]
2022-03-23 Fixed some more clearance issues
    [erun2.kicad_pcb]
2022-03-24 Added capacitors to the board
    [erun2.kicad_pcb, erun2.kicad_sch]
2022-03-24 Added filled zones
    [erun2.kicad_pcb]
2022-03-24 Added vias to filled zones
    [erun2.kicad_pcb]
2022-03-24 Fixed a label
    [erun2.kicad_pcb]
2022-04-13 Added low pass filter and minor refinements
    [erun2.kicad_pcb, erun2.kicad_sch]
2022-04-14 Updated some labels
    [erun2.kicad_pcb, erun2.kicad_sch]
2022-04-14 Very minor fixes
    [erun2.kicad_pcb]
2022-05-04 Added page for calibration
2022-05-19 Added backend support for zeroing the encoder
2022-05-25 PCB 2.1, fixed ADC and moved analog input
    [erun2.kicad_sch]
2022-05-31 Added reading from actual sensors
2022-06-07 Added webapp support for real sensor values and coefficients
2022-06-08 Fixed bug where the stop command did not work
    [main.cpp]
2022-06-13 Added calibration plotting and regression
2022-06-13 Calibrations can now be selected
2022-06-13 Added sensor name inputs
2022-06-20 Disabled button for invalid calibrations
2022-06-20 Added frontend support for creating empty calibrations
2022-06-20 Starting measurement on calibration tab now appends to an existing calibration
2022-06-20 Removed sample speed
2022-06-23 Measurements and calibrations are now split in frotend
    Squash: Measurements and calibrations are now stored in one place
2022-06-23 Added support for deleting all calibrations
2022-06-27 Improved teensy responsiveness by decreasing serial timeout
2022-06-27 Revamped measurement data structure and calibration
2022-06-28 Added control buttons for MCU connection
2022-06-28 Changed calibration chart colors
2022-07-04 Added voltage divider
    [erun2.kicad_pcb, erun2.kicad_sch]
2022-07-05 Hid broken download button
2022-07-21 First version of PCB board v3.0
    [erun2.kicad_pcb, erun2.kicad_sch]
2022-07-26 Changed SW1 hole shape and added analog text
    [erun2.kicad_pcb]
2022-07-27 Fixed trace overlapping with hole and changed MCP3301 package from MSOP to SOIC
    [erun2.kicad_pcb, erun2.kicad_sch]
2022-08-16 Added informative text for sample count
2022-08-16 Removed 'Reconnect MCU' button
2022-08-17 Starting and stopping measurement with single button
2022-08-17 Sample mode is now changed from a select dropdown
2022-08-17 Moved Measure and Calibrate pages to components folder
2022-08-17 Added 'disabled' prop for StartStopButton
2022-08-17 Added selected calibration info text
2022-08-17 Added confirmation to delete all button
2022-08-17 Added print button for measurement modal
2022-08-22 Added measurement status info to Calibrate tab
